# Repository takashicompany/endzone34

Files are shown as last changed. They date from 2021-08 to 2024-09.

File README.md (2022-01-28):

# EndZone34
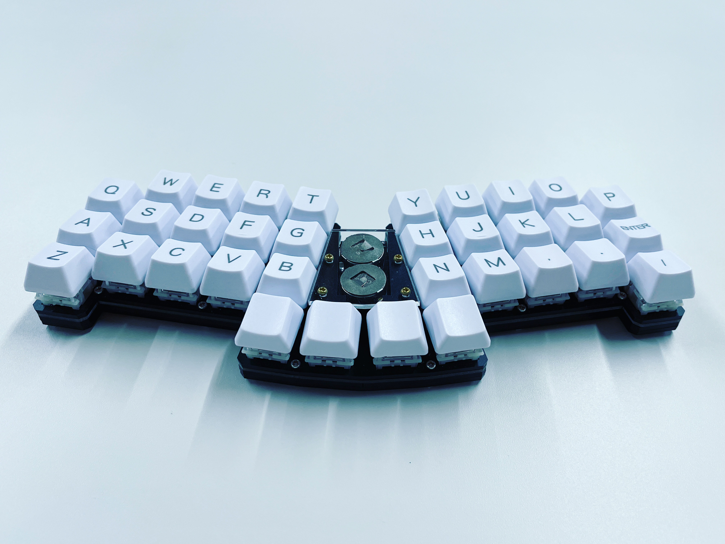
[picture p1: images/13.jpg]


ミニマルな34キーのキーボードです。  
LEDとOLED、MXソケットに対応しています。

# 組み立て方

## ビルドログ

- [いとうひよこさんのNote](https://note.com/tsubuan_145/n/n91b1f3b4b958)

## 1. 部品の確認

### キットに同梱されているもの

|項目|個数|備考|
|:--|:--|:--|
|PCB|1|
|トッププレート|1|
|ボトムプレート|1|
|側面プレート|2|左右有り。キースイッチをMXソケットで取り付ける場合は不要|
|ProMicroプレート|1|
|ProMicro側面プレート|2|
|M2ネジ 10mm|18|
|M2ナット|18|
|ダイオード|34|
|リセットスイッチ|1|
|ゴム足シール|8|

### ご自身で用意されるもの
|項目|個数|備考|
|:--|:--|:--|
|キースイッチ|34|Cherry MX互換|
|キーキャップ|34|
|Pro Micro|1|必要な場合はコンスルーもご用意ください|

### MXソケットを利用する際に必要な部品

PCBがMXソケットに対応しているため、スペーサーとネジを別途ご用意頂き、キースイッチの付け替えが可能になります。
(MXソケットを使用する場合は側面プレートを取り付けることはできません。)

|項目|個数|備考|
|:--|:--|:--|
|MXソケット|34||
|両雌ネジスペーサー 7mm|8|
|M2ネジ 4mm|16|

## 2. ダイオードのはんだ付け

### ① PCBの裏表の確認

**こちらが表面**  


**こちらは裏面**  


はんだ付けは**裏面**に行います

### ① マスキングテープで表面にはんだが漏れないようにする

(テープを見えやすくするために黒色のPCBで説明します)  


当キットではトッププレートとPCBを密着させる方式なので、表面にはんだが漏れて凹凸ができないように、マスキングテープなどで穴を塞ぎましょう。

### ② ダイオードをはんだづけする

https://user-images.githubusercontent.com/4215759/126895350-43ae4cd4-408b-4ff4-ab5c-2903e0420978.mov

PCBのダイオードのはんだづけ箇所の片方にはんだを乗せておき(予備はんだ)、ピンセットでダイオードを持ちながら予備はんだを溶かしながらダイオードをはんだづけします。  
片方のはんだづけが終わったら、動画と同じく反対側をはんだづけしましょう。



全部で34箇所あります。

## 3-a. キースイッチのはんだ付け

キースイッチをはんだ付けする場合は、以下の手順になります。

### ① トッププレートを取り出す

アクリル製のトッププレートを取り出します。  


ネジ穴部分にアクリル栓が詰まっている場合は、ピンセットやネジで押し出すと取り出すことができます。  
全てのネジ穴が空いていることを確認しましょう。  


トッププレートの台紙を剥がします。   
剥がしづらい場合は、台紙を少し濡らすと剥がれやすくなります。


下記の画像のように両面を剥がします。  


### ② トッププレートを仮止め

当キーボードキットは、PCBとトッププレートを密着させる必要があるため、キースイッチのはんだ付けの際にトッププレートがぐらつかないようにすると作業が楽になります。  
同梱しているネジとナットを使って、PCBの表側にトッププレートを固定しましょう。


あくまで仮止めですので、全ての箇所を固定しなくても問題ありません。
下記の画像は目安です。  
固定できたらPCBとトッププレートに隙間が無いことを確認してください。


### ③ キースイッチをはんだ付けする
PCBとトッププレートを固定できたら、キースイッチのはんだ付けを行います。  
キースイッチがズレないように、マスキングテープなどで固定すると作業が楽になります。


各キースイッチ、2箇所をはんだ付けします。  
**取付箇所毎にキースイッチの向きが異なります。**  


34個のキースイッチをはんだ付けできたら、高さがズレているものがないかを確認します。  
加えて、再びPCBとトッププレートの間に隙間が無いことを確認します。


## 3-b. MXソケットでキースイッチを取り付ける場合

キースイッチをMXソケットではんだ付けする際は、以下の方法になります。
なお、この場合は側面プレートではなく、スペーサーでトッププレートとボトムプレートを固定することとなります。

### ① PCBにMXソケットをはんだ付けする


### ② トッププレートを取り出す

「3-a. ① トッププレートを取り出す」と同様にトッププレートを取りだします。

### ③ トッププレートにキースイッチを取り付ける

PCBとトッププレートの仮止めとして、キースイッチを数個取り付けます。


以下は一例になります。  


キースイッチをいくつか取り付けた後に、PCBにはんだ付けしたMXソケットにトッププレートに仮止めしたキースイッチを取り付けます。


トッププレートがたわまないように気をつけながら、全てのMXソケットにキースイッチを付けていきます。


### ④ トッププレートにスペーサーを取り付ける

以下の赤丸の箇所にスペーサーを取り付けます。  
トッププレートとスペーサーをネジで固定します。  


下記の写真のように、トッププレートからネジで固定されたスペーサーがPCBを貫通してPCBの裏側に出ていると正しく取り付けられています。


## 4. リセットスイッチのはんだ付け
※リセットスイッチのはんだ付けは必須ではありません。組み立て後も、ピンセット等を用いて底面からリセット操作が可能です。

### ① PCBの裏面からリセットスイッチを差し込む


### ② PCBの表面からはんだづけをする


### ③ はんだ付けした部分を可能な限り平らにする


Pro Microとぶつかってしまう可能性があるので、ニッパーなどで平らにします。



### ④ 絶縁テープなどではんだ付け部分を覆う



## 5. Pro Microの取り付け

Pro Microをご用意いただきます。  
PCBはコンスルーとはんだ付けの両対応をしています。  


Pro Microのチップなどが載っていない方を表側にし、PCBの表側に指します。


一度ここで、ProMicroをPCなどに繋ぎ、ファームウェアを焼いて動作確認をすると問題があった際に、対処が容易です。  


ファームウェアは[こちら](https://github.com/takashicompany/endzone34/blob/master/README.md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)。

## 6. Pro Microプレートの取り付け
まずはPro Microの側面プレートを取り付けます。  
側面プレートは二種類あるので、お好みで選んでください。  


台紙を剥がして、側面プレートを2枚トッププレートに載せます。    


次にPro Microプレートを取り付けます。  


台紙を剥がして、側面プレートの上に載せます。  


ネジとナットで固定します。  


裏面は下記の写真のようにナットで抑えます。  


MXソケットを利用する場合は、ナットの代わりにスペーサーを用いると良いです。

## 6. LEDの取り付け

LEDの取り付けは必須ではありません。一度組み立てた後で取り付けることでも可能です。  
LEDはWS2812Bを使用します。下記の画像の順番で取り付けます。 


取り付ける際に、PCBのプリント(角の塗りつぶし)とLEDの角の向きが合うようにします。 


まずは予備ハンダをします。利き腕側で手前の側の部分からはんだ付けをすると楽にできます。


一つのLEDの4箇所をはんだづけします。  


一つはんだ付けができたら、LEDが光るかを確認しましょう。  
USBでPCにキーボードを接続した後、`RGB_TOG`キーを押して、LEDが光るかを確認します。  


全部で9つのLEDを取り付けられることができます。  


## 7. ケースの組み立て

※ MXソケットでキースイッチを固定する場合は、側面プレートを取り付けることができません。

側面プレートを取りだします。側面プレートは左右で分かれています。


ボトムプレートも取りだします。  


台紙を取り外して、側面プレートとボトムプレートをネジとナットで取り付けます。




側面プレートとボトムプレートを取り付けた後は、ゴム足をケースに貼ります。


### MXソケットでキースイッチを取り付けた場合

以下の赤丸の箇所をネジ止めします。  


# 8. ファームウェア

## [QMK Firmware](https://github.com/qmk/qmk_firmware)
- QMK Firmware公式に[マージ済み](https://github.com/qmk/qmk_firmware/pull/13847)です
- [keyboards/takashicompany/endzone34](https://github.com/qmk/qmk_firmware/tree/master/keyboards/takashicompany/endzone34)にファームウェアを用意しております。

## VIA用のファームウェアは[こちら](https://github.com/takashicompany/endzone34/releases/download/via-0.0.3/takashicompany_endzone34_via.hex)
- [Remap](https://remap-keys.app/)へ登録済みですので、上記のVIA対応したファームウェアをPro Microに書き込むことでブラウザからキーマップの変更が可能です。
- (2021/09/01) OLEDの表示とレイヤー数を8にしたファームウェアを追加しました。

# 9. OLEDが点灯しない場合
ファームウェアの容量の関係でVIAのファームウェアにOLEDが入っていないことがあります。  
疎通を確認するために、[デフォルトのファームウェア](https://github.com/takashicompany/endzone34/releases/download/via-0.0.2/takashicompany_endzone34_default.hex)で一度OLEDの確認をお願いします。

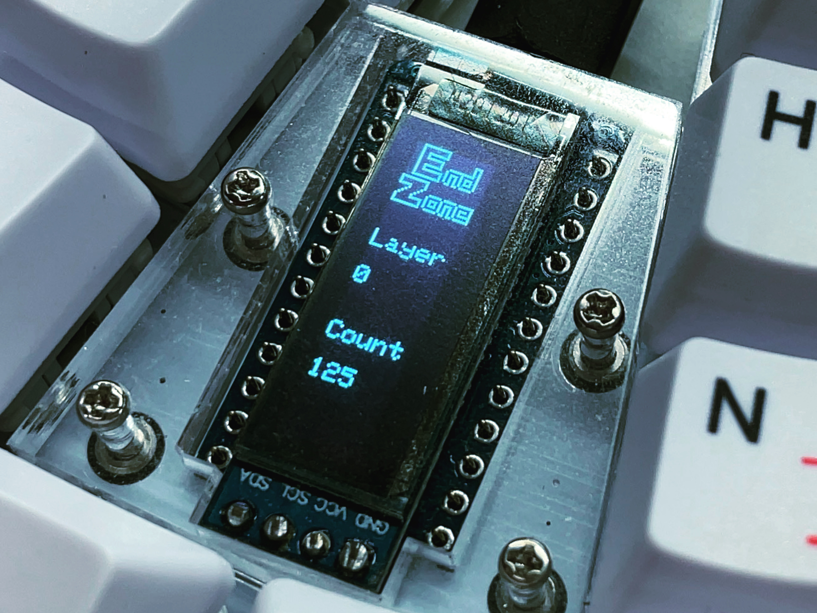
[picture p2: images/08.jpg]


# 10. 自慢する

完成しましたら、ぜひSNSなどに写真を投稿頂ければと思います。  
Twitterのハッシュタグは`#EndZone34`を付けていただけば幸いです。  
キットを組み立てた感想や、キーボードを使った所感などをお待ちしております！  

また、毎週日曜日の１9時より実施されている[#KEEP_PD](https://twitter.com/hashtag/KEEB_PD?f=live)に投稿頂くこともオススメです。  
開催の告知は[@KEEB_PD](https://twitter.com/KEEB_PD)にて行われております。

ご不明な点などございましたら、[@takashicompany](https://twitter.com/takashicompany)にメンションやDM頂ければと思います！

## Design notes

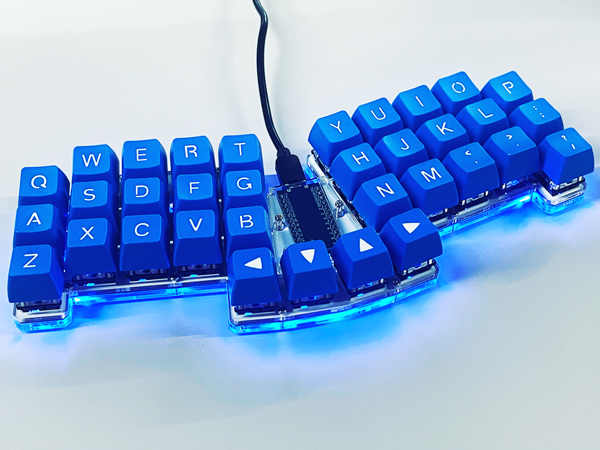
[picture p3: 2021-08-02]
images/main_qmk.jpg

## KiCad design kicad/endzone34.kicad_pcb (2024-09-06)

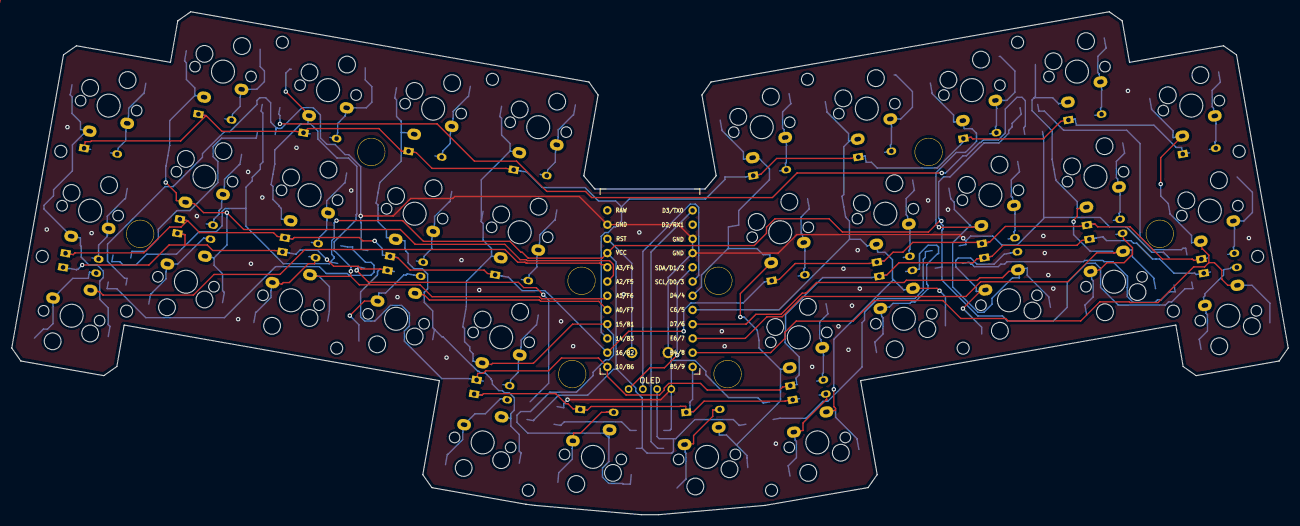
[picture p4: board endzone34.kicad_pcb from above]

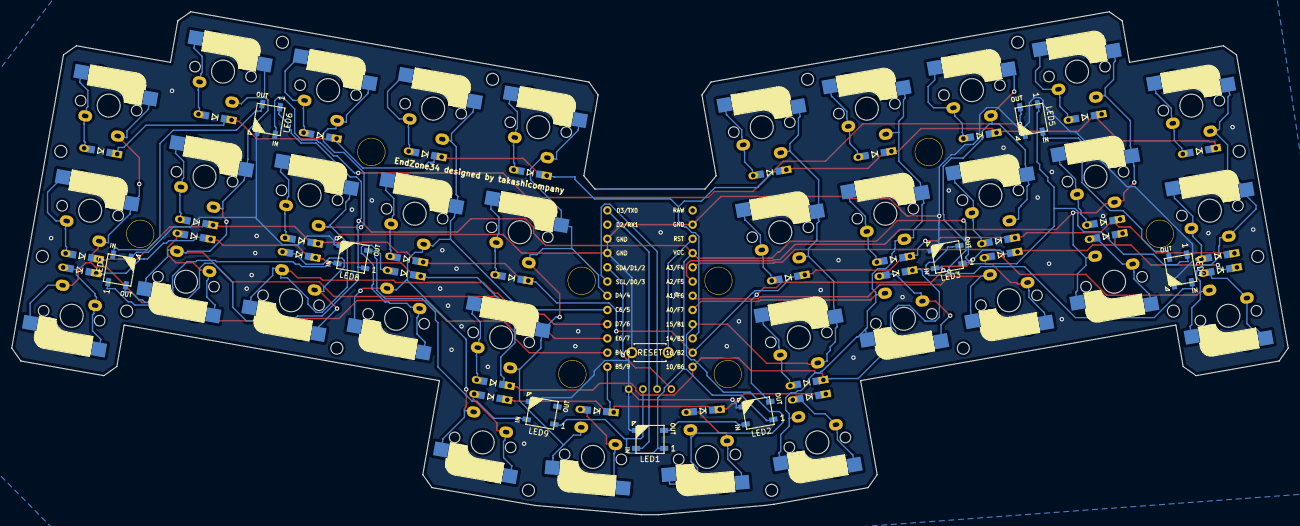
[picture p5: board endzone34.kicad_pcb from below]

Board: 2 copper layers, 227.9 x 89.8 mm, 102 parts (44 on the bottom side), 62 nets.

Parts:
D1, D2, D3, D4, D5, D6, D7, D8, D9, D10, D11, D12, D13, D14, D15, D16, D17, D18, D19, D20, D21, D22, D23, D24, D25, D26, D27, D28, D29, D30, D31, D32, D33, D34: DIODE; D3_TH_SMD_v2
LED1, LED2, LED3, LED4, LED5, LED6, LED7, LED8, LED9: WS2812B
OL1: OLED; OLED_v2
RESET_SW1: SW_Push; ResetSW_1side
Ref01, Ref02, Ref03, Ref04, Ref05, Ref06, Ref007, Ref08: Val**; HOLE
Ref11, Ref12, Ref13, Ref14, Ref15, Ref16, Ref17, Ref18, Ref19, Ref20, Ref21, Ref22, Ref23, Ref24: M2_Hole
SW1, SW2, SW3, SW4, SW5, SW6, SW7, SW8, SW9, SW10, SW11, SW12, SW13, SW14, SW15, SW16, SW17, SW18, SW19, SW20, SW21, SW22, SW23, SW24, SW25, SW26, SW27, SW28, SW29, SW30, SW31, SW32, SW33, SW34: SW_Push; CherryMX_TH-Hotswap
U1: ProMicro_r; ProMicro_v3.5_print-inside

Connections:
GND: LED1.3, LED2.3, LED3.3, LED4.3, LED5.3, LED6.3, LED7.3, LED8.3, LED9.3, OL1.4, RESET_SW1.2, U1.3, U1.4, U1.23
unnamed: D1.2, SW1.2
unnamed: D2.2, SW2.2
unnamed: D3.2, SW3.2
unnamed: D4.2, SW4.2
unnamed: D5.2, SW5.2
unnamed: D6.2, SW6.2
unnamed: D7.2, SW7.2
unnamed: D8.2, SW8.2
unnamed: D9.2, SW9.2
unnamed: D10.2, SW10.2
unnamed: D11.2, SW11.2
unnamed: D12.2, SW12.2
unnamed: D13.2, SW13.2
unnamed: D14.2, SW14.2
unnamed: D15.2, SW15.2
unnamed: D16.2, SW16.2
unnamed: D17.2, SW17.2
unnamed: D18.2, SW18.2
unnamed: D19.2, SW19.2
unnamed: D20.2, SW20.2
unnamed: D21.2, SW21.2
unnamed: D22.2, SW22.2
unnamed: D23.2, SW23.2
unnamed: D24.2, SW24.2
unnamed: D25.2, SW25.2
unnamed: D26.2, SW26.2
unnamed: D27.2, SW27.2
unnamed: D28.2, SW28.2
unnamed: D29.2, SW29.2
unnamed: D30.2, SW30.2
unnamed: D31.2, SW31.2
unnamed: D32.2, SW32.2
unnamed: D33.2, SW33.2
unnamed: D34.2, SW34.2
unnamed: LED1.2, LED2.4
unnamed: LED2.2, LED3.4
unnamed: LED3.2, LED4.4
unnamed: LED4.2, LED5.4
unnamed: LED5.2, LED6.4
unnamed: LED6.2, LED7.4
unnamed: LED7.2, LED8.4
unnamed: LED8.2, LED9.4
SCL: OL1.2, U1.6
SDA: OL1.1, U1.5
VCC: LED1.1, LED2.1, LED3.1, LED4.1, LED5.1, LED6.1, LED7.1, LED8.1, LED9.1, OL1.3, U1.21
col0: SW1.1, SW11.1, SW21.1, U1.20
col1: SW2.1, SW12.1, SW22.1, U1.19
col2: SW3.1, SW13.1, SW23.1, U1.18
col3: SW4.1, SW14.1, SW24.1, SW31.1, U1.17
col4: SW5.1, SW15.1, SW25.1, SW32.1, U1.16
col5: SW6.1, SW16.1, SW26.1, SW33.1, U1.7
col6: SW7.1, SW17.1, SW27.1, SW34.1, U1.8
col7: SW8.1, SW18.1, SW28.1, U1.9
col8: SW9.1, SW19.1, SW29.1, U1.10
col9: SW10.1, SW20.1, SW30.1, U1.11
led: LED1.4, U1.1
reset: RESET_SW1.1, U1.22
row0: D1.1, D2.1, D3.1, D4.1, D5.1, D6.1, D7.1, D8.1, D9.1, D10.1, U1.15
row1: D11.1, D12.1, D13.1, D14.1, D15.1, D16.1, D17.1, D18.1, D19.1, D20.1, U1.14
row2: D21.1, D22.1, D23.1, D24.1, D25.1, D26.1, D27.1, D28.1, D29.1, D30.1, U1.13
row3: D31.1, D32.1, D33.1, D34.1, U1.12

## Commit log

2021-07-25 概要を書いた
2021-07-25 画像や動画を入れた
2021-07-25 画像の表示方法をHTML型に
2021-07-31 途中まで書いた
2021-07-31 MXソケットに対しての記述
2021-08-01 とりあえず書いた。
2021-08-01 写真の改行を整理
2021-08-01 画像を追加
2021-08-01 画像のパスを変更
2021-08-02 画像を更新
2021-08-02 リネーム
2021-08-02 ガーバーファイルをアップロード
2021-08-06 ファームウェアに関して書いた
2021-08-06 VIAのファームウェアへのリンク
2021-08-06 ファームウェアへのジャンプ
2021-08-07 Remapのことを書いた
2021-08-13 QMK公式にマージされたので、その内容を記載
2021-08-22 説明書を修正
2021-08-26 MXソケットに関する記載を追加
2021-08-26 改行を修正
2021-08-30 OLEDの件を追加
2021-08-31 OLEDの項目を足しました
2021-09-18 写真を追加
2021-10-27 画像の追加”
